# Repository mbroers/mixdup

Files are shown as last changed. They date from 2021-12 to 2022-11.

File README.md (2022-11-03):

# mixdup
teensy based midi controller

Based on the awesome [Control Surface](https://github.com/tttapa/Control-Surface) teensyduino library.

v1 has two rows of switches and uses teensy 3.2

v2 has 3 rows of switches, ICs moved to back of board so they are socketable (this resulted in a change to the teensy code as well), and the pots/sliders are a bit more spaced out along with some other minor cleanups. Still uses teensy 3.2

v3 is for teensy 4.1

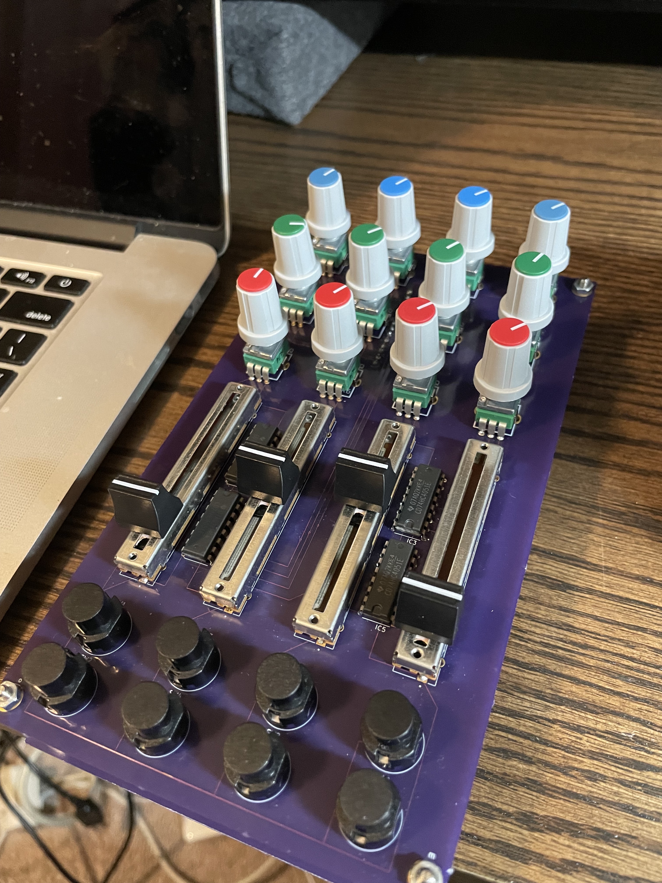
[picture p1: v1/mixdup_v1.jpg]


Forthcoming
- [ ] Panel vector/FPE files
- [ ] Enclosure plans
- [ ] Expander with Effects Racks capabilities and 5 band eq
- [ ] Live macros to create default map

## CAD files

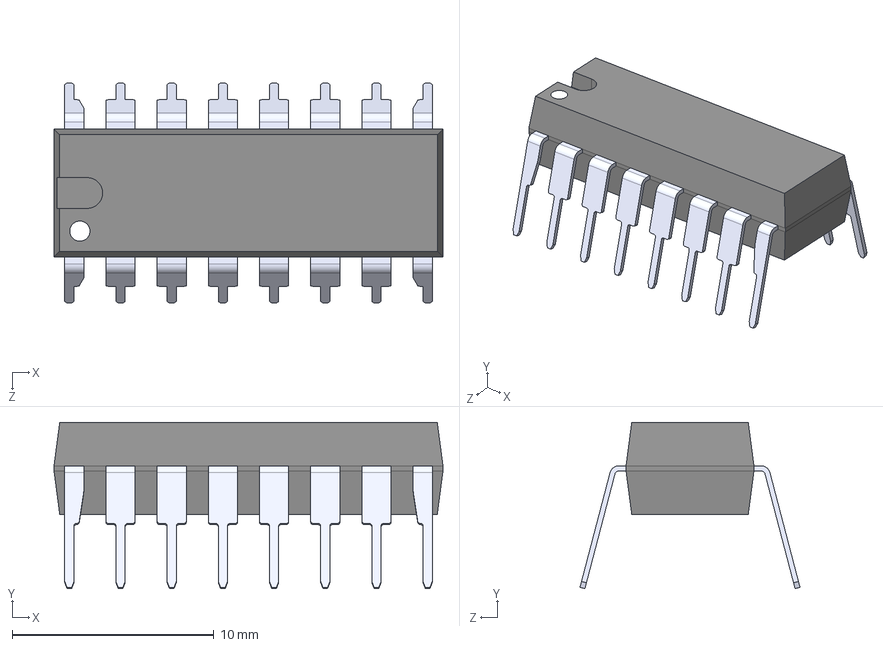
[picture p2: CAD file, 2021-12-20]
kicad_libraries/CD74HC4051E/CD74HC4051E.step
19.3 x 8.25 x 10.9 mm

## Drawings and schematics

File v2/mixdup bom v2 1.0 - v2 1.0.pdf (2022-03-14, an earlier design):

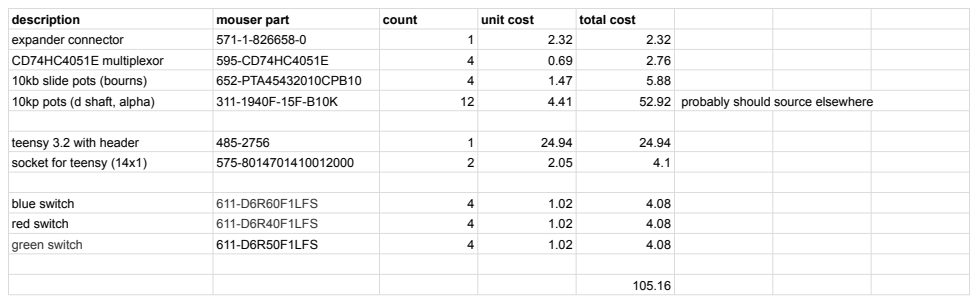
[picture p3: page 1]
description; mouser part; count; unit cost; total cost; expander connector; CD74HC4051E multiplexor; 10kb slide pots (bourns); 652-PTA45432010CPB10; 10kp pots (d shaft, alpha); 52.92 probably should source elsewhere; teensy 3.2 with header; socket for teensy (14x1)

blue switch red switch | 611-D6R60F1LFS 611-D6R40F1LFS | 4 1.02 4.08

green switch | 611-D6R50F1LFS 4 1.02 4.08

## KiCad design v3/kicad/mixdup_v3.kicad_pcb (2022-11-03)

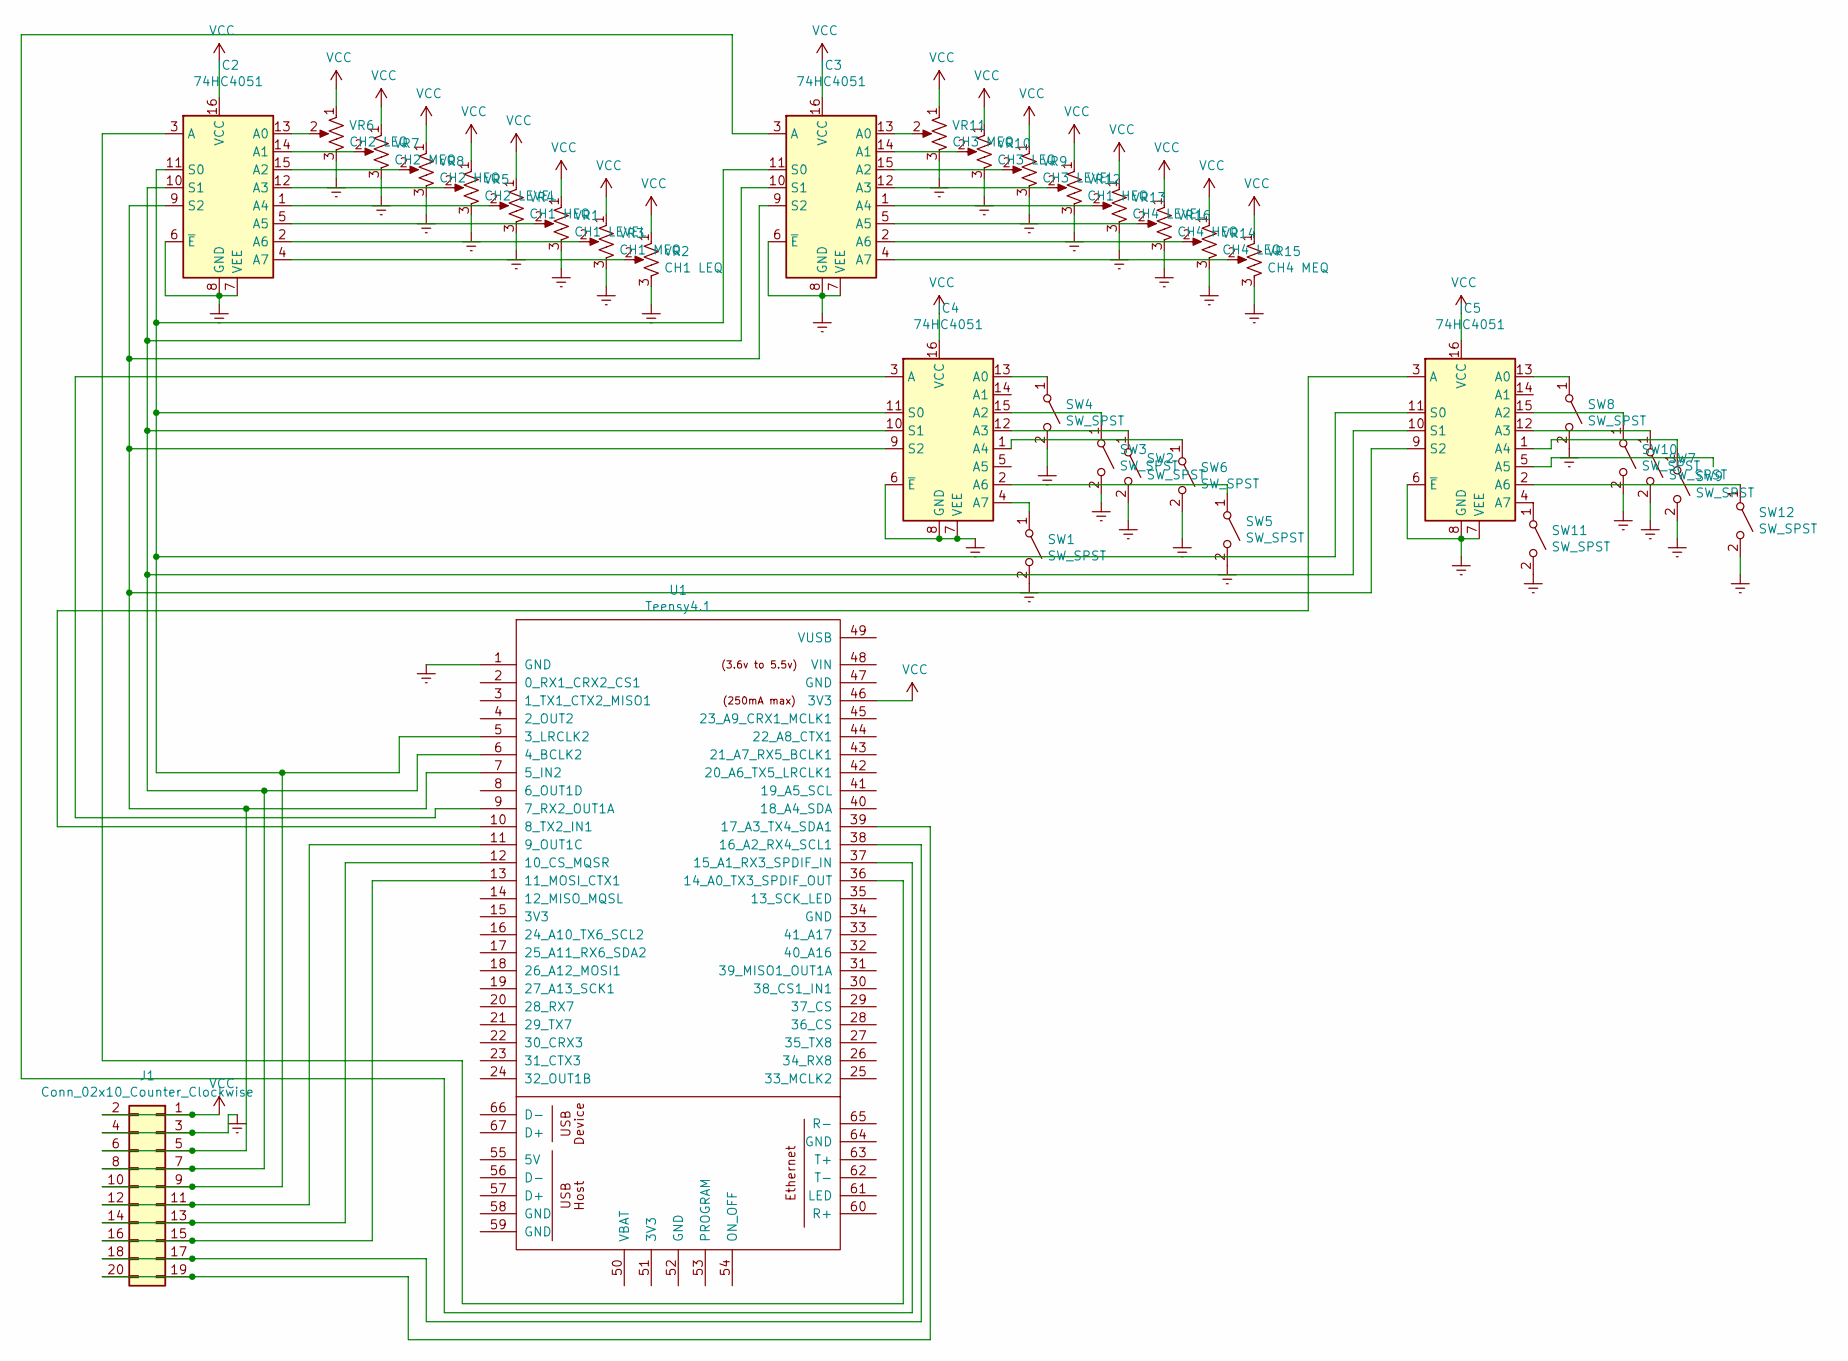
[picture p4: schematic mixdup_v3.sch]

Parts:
IC2, IC3, IC4, IC5: 74HC4051; DIP794W45P254L1969H508Q16
J1: Conn_02x10_Counter_Clockwise; PinHeader_2x10_P2.54mm_Vertical
SW1, SW2, SW3, SW4, SW5, SW6, SW7, SW8, SW9, SW10, SW11, SW12: SW_SPST; SW_D6R90_F1_LFS
U1: Teensy4.1; Teensy41
VR1: CH1 LEVEL; PTA4543-2015DPA103
VR2: CH1 LEQ; RD901F-ALPHA-POT
VR3: CH1 MEQ; RD901F-ALPHA-POT
VR4, VR12: CH1 HEQ; RD901F-ALPHA-POT
VR5: CH2 LEVEL; PTA4543-2015DPA103
VR6: CH2 LEQ; RD901F-ALPHA-POT
VR7: CH2 MEQ; RD901F-ALPHA-POT
VR8: CH2 HEQ; RD901F-ALPHA-POT
VR9: CH3 LEVEL; PTA4543-2015DPA103
VR10: CH3 LEQ; RD901F-ALPHA-POT
VR11: CH3 MEQ; RD901F-ALPHA-POT
VR13: CH4 LEVEL; PTA4543-2015DPA103
VR14: CH4 LEQ; RD901F-ALPHA-POT
VR15: CH4 MEQ; RD901F-ALPHA-POT
VR16: CH4 HEQ; RD901F-ALPHA-POT

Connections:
Earth: IC2.6 (~E), IC2.7 (VEE), IC2.8 (GND), IC3.6 (~E), IC3.7 (VEE), IC3.8 (GND), IC4.6 (~E), IC4.7 (VEE), IC4.8 (GND), IC5.6 (~E), IC5.7 (VEE), IC5.8 (GND), J1.3, J1.4, SW1.2 (B), SW2.2 (B), SW3.2 (B), SW4.2 (B), SW5.2 (B), SW6.2 (B), SW7.2 (B), SW8.2 (B), SW9.2 (B), SW10.2 (B), SW11.2 (B), SW12.2 (B), U1.1 (GND), VR1.3, VR2.3, VR3.3, VR4.3, VR5.3, VR6.3, VR7.3, VR8.3, VR9.3, VR10.3, VR11.3, VR12.3, VR13.3, VR14.3, VR15.3, VR16.3
unnamed: IC2.1 (A4), VR4.2
unnamed: IC2.2 (A6), VR3.2
unnamed: IC2.3 (A), U1.36 (14_A0_TX3_SPDIF_OUT)
unnamed: IC2.4 (A7), VR2.2
unnamed: IC2.5 (A5), VR1.2
unnamed: IC2.9 (S2), IC3.9 (S2), IC4.9 (S2), IC5.9 (S2), J1.5, J1.6, U1.7 (5_IN2)
unnamed: IC2.10 (S1), IC3.10 (S1), IC4.10 (S1), IC5.10 (S1), J1.7, J1.8, U1.6 (4_BCLK2)
unnamed: IC2.11 (S0), IC3.11 (S0), IC4.11 (S0), IC5.11 (S0), J1.9, J1.10, U1.5 (3_LRCLK2)
unnamed: IC2.12 (A3), VR5.2
unnamed: IC2.13 (A0), VR6.2
unnamed: IC2.14 (A1), VR7.2
unnamed: IC2.15 (A2), VR8.2
unnamed: IC3.1 (A4), VR13.2
unnamed: IC3.2 (A6), VR14.2
unnamed: IC3.3 (A), U1.37 (15_A1_RX3_SPDIF_IN)
unnamed: IC3.4 (A7), VR15.2
unnamed: IC3.5 (A5), VR16.2
unnamed: IC3.12 (A3), VR12.2
unnamed: IC3.13 (A0), VR11.2
unnamed: IC3.14 (A1), VR10.2
unnamed: IC3.15 (A2), VR9.2
unnamed: IC4.1 (A4), SW6.1 (A)
unnamed: IC4.2 (A6), SW5.1 (A)
unnamed: IC4.3 (A), U1.9 (7_RX2_OUT1A)
unnamed: IC4.4 (A7), SW1.1 (A)
unnamed: IC4.12 (A3), SW2.1 (A)
unnamed: IC4.13 (A0), SW4.1 (A)
unnamed: IC4.15 (A2), SW3.1 (A)
unnamed: IC5.1 (A4), SW9.1 (A)
unnamed: IC5.2 (A6), SW12.1 (A)
unnamed: IC5.3 (A), U1.10 (8_TX2_IN1)
unnamed: IC5.4 (A7), SW11.1 (A)
unnamed: IC5.12 (A3), SW7.1 (A)
unnamed: IC5.13 (A0), SW8.1 (A)
unnamed: IC5.15 (A2), SW10.1 (A)
unnamed: J1.11, J1.12, U1.11 (9_OUT1C)
unnamed: J1.13, J1.14, U1.12 (10_CS_MQSR)
unnamed: J1.15, J1.16, U1.13 (11_MOSI_CTX1)
unnamed: J1.17, J1.18, U1.38 (16_A2_RX4_SCL1)
unnamed: J1.19, J1.20, U1.39 (17_A3_TX4_SDA1)
VCC: IC2.16 (VCC), IC3.16 (VCC), IC4.16 (VCC), IC5.16 (VCC), J1.1, J1.2, U1.46 (3V3), VR1.1, VR2.1, VR3.1, VR4.1, VR5.1, VR6.1, VR7.1, VR8.1, VR9.1, VR10.1, VR11.1, VR12.1, VR13.1, VR14.1, VR15.1, VR16.1

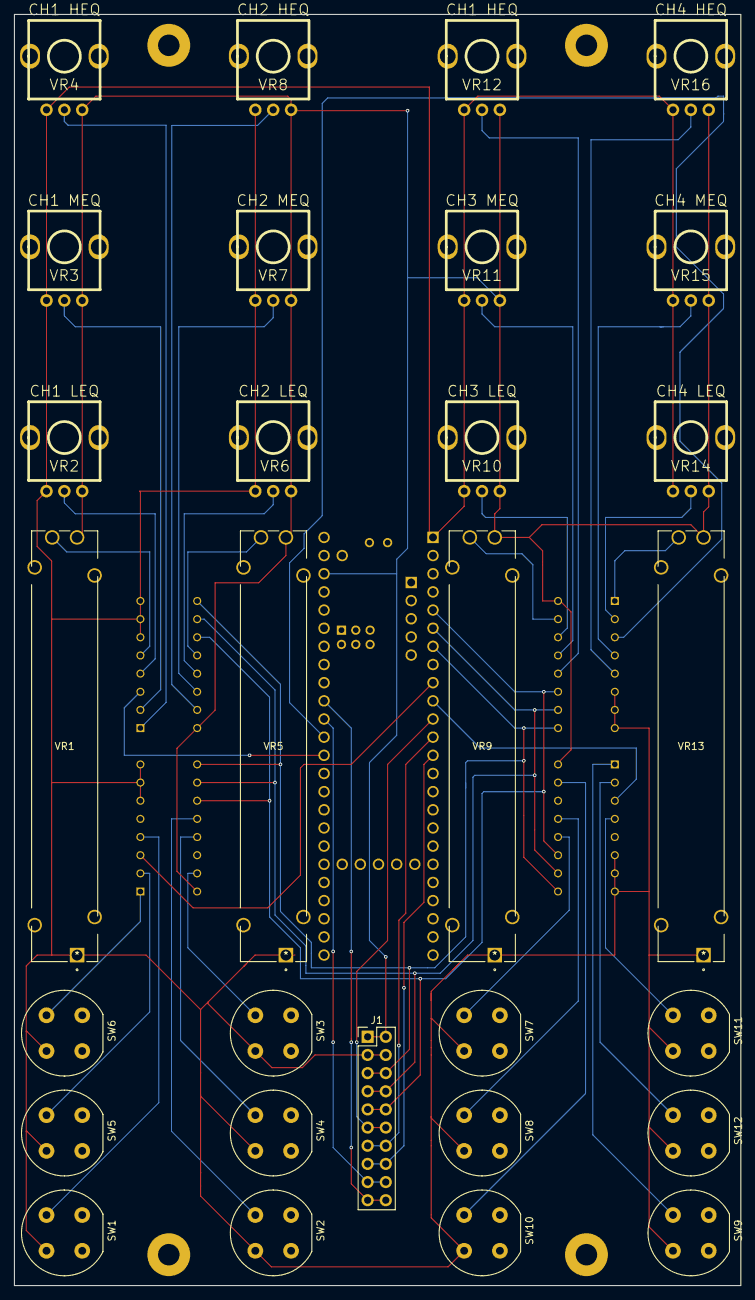
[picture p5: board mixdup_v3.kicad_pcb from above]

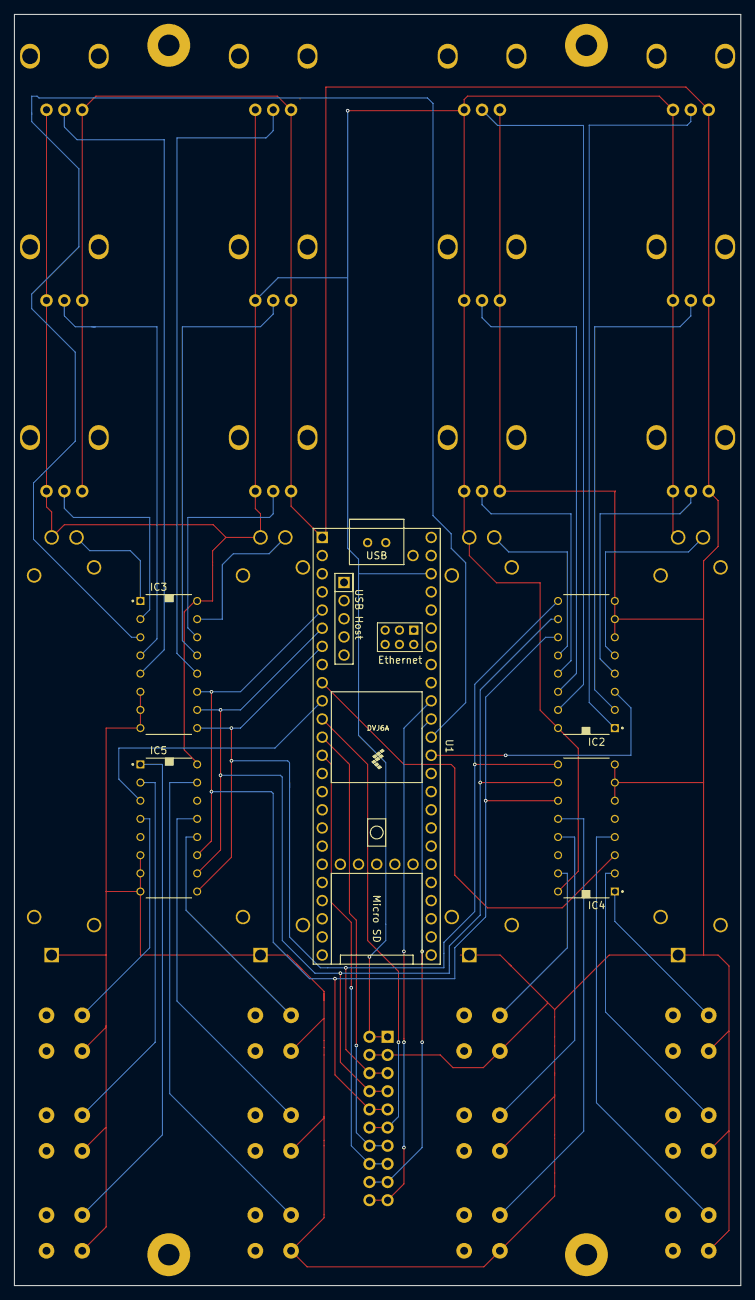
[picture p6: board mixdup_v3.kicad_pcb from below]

Board: 2 copper layers, 101.6 x 177.8 mm, 34 parts (5 on the bottom side), 42 nets.

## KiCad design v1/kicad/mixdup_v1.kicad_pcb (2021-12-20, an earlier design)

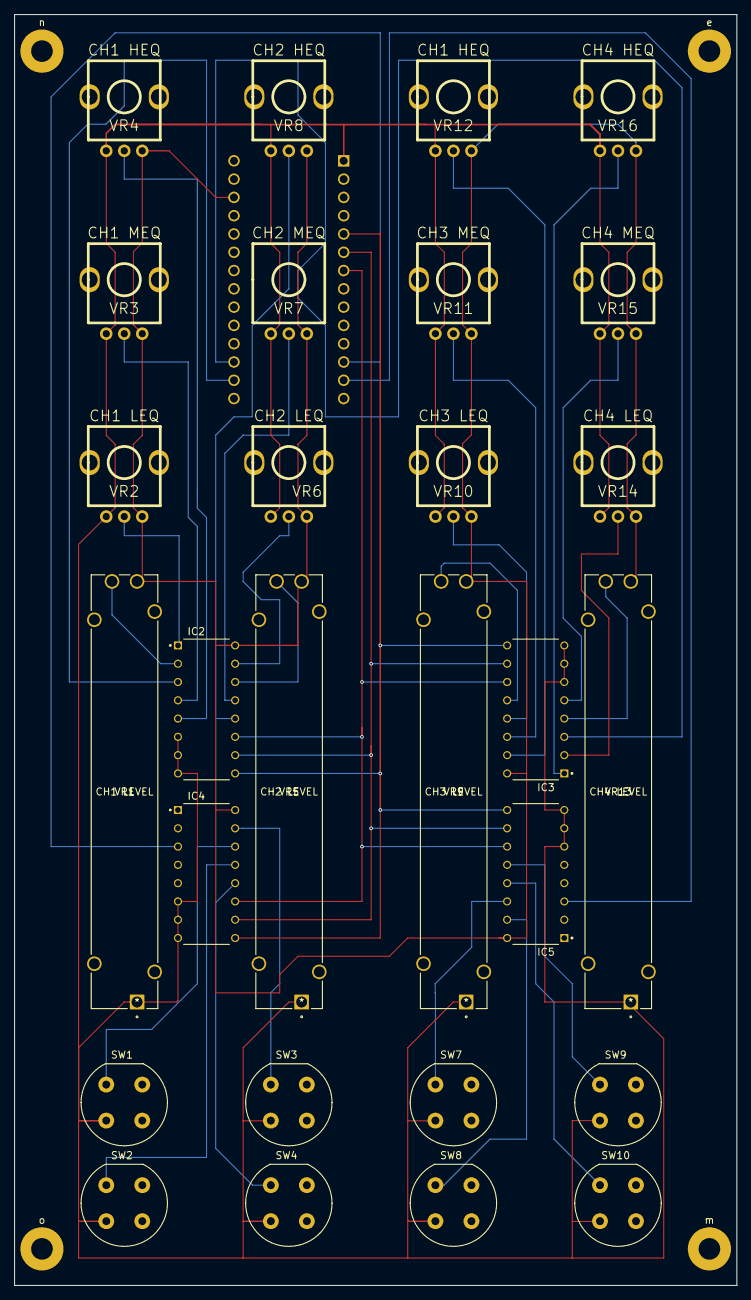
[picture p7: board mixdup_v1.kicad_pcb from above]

Board: 2 copper layers, 100.3 x 176.5 mm, 33 parts (1 on the bottom side), 33 nets.

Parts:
IC1: Teensy3.2; Teensy30_31_32_Some_Pins_MB
IC2, IC3, IC4, IC5: 74HC4051; DIP794W45P254L1969H508Q16
SW1, SW2, SW3, SW4, SW7, SW8, SW9, SW10: SW_SPST; SW_D6R90_F1_LFS
VR1: CH1 LEVEL; PTA4543-2015DPA103
VR2: CH1 LEQ; RD901F-ALPHA-POT
VR3: CH1 MEQ; RD901F-ALPHA-POT
VR4, VR12: CH1 HEQ; RD901F-ALPHA-POT
VR5: CH2 LEVEL; PTA4543-2015DPA103
VR6: CH2 LEQ; RD901F-ALPHA-POT
VR7: CH2 MEQ; RD901F-ALPHA-POT_MB_overteensy
VR8: CH2 HEQ; RD901F-ALPHA-POT
VR9: CH3 LEVEL; PTA4543-2015DPA103
VR10: CH3 LEQ; RD901F-ALPHA-POT
VR11: CH3 MEQ; RD901F-ALPHA-POT
VR13: CH4 LEVEL; PTA4543-2015DPA103
VR14: CH4 LEQ; RD901F-ALPHA-POT
VR15: CH4 MEQ; RD901F-ALPHA-POT
VR16: CH4 HEQ; RD901F-ALPHA-POT
e: e; MountingHole_3mm_Pad
m: m; MountingHole_3mm_Pad
n: n; MountingHole_3mm_Pad
o: o; MountingHole_3mm_Pad

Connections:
Earth: IC1.1, IC2.6, IC2.7, IC2.8, IC3.6, IC3.7, IC3.8, IC4.6, IC4.7, IC4.8, IC5.6, IC5.7, IC5.8, SW1.2, SW2.2, SW3.2, SW4.2, SW7.2, SW8.2, SW9.2, SW10.2, VR1.3, VR2.3, VR3.3, VR4.3, VR5.3, VR6.3, VR7.3, VR8.3, VR9.3, VR10.3, VR11.3, VR12.3, VR13.3, VR14.3, VR15.3, VR16.3
unnamed: IC1.5, IC2.9, IC3.9, IC4.9, IC5.9
unnamed: IC1.6, IC2.10, IC3.10, IC4.10, IC5.10
unnamed: IC1.7, IC2.11, IC3.11, IC4.11, IC5.11
unnamed: IC1.12, IC4.3
unnamed: IC1.13, IC5.3
unnamed: IC1.21, IC2.3
unnamed: IC1.22, IC3.3
unnamed: IC2.1, VR2.2
unnamed: IC2.2, VR1.2
unnamed: IC2.4, VR3.2
unnamed: IC2.5, VR4.2
unnamed: IC2.12, VR8.2
unnamed: IC2.13, VR7.2
unnamed: IC2.14, VR5.2
unnamed: IC2.15, VR6.2
unnamed: IC3.1, VR16.2
unnamed: IC3.2, VR14.2
unnamed: IC3.4, VR13.2
unnamed: IC3.5, VR15.2
unnamed: IC3.12, VR9.2
unnamed: IC3.13, VR10.2
unnamed: IC3.14, VR11.2
unnamed: IC3.15, VR12.2
unnamed: IC4.12, SW4.1
unnamed: IC4.13, SW2.1
unnamed: IC4.14, SW1.1
unnamed: IC4.15, SW3.1
unnamed: IC5.12, SW9.1
unnamed: IC5.13, SW10.1
unnamed: IC5.14, SW7.1
unnamed: IC5.15, SW8.1
VCC: IC1.31, IC2.16, IC3.16, IC4.16, IC5.16, VR1.1, VR2.1, VR3.1, VR4.1, VR5.1, VR6.1, VR7.1, VR8.1, VR9.1, VR10.1, VR11.1, VR12.1, VR13.1, VR14.1, VR15.1, VR16.1

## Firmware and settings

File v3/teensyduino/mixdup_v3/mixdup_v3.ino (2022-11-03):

#include <Control_Surface.h>

USBMIDI_Interface mixdup;

CD74HC4051 mux1 {
  A0,       // Analog input pin
  {3, 4, 5} // Address pins S0, S1, S2
};

CD74HC4051 mux2 {
  7,       // digital input pin
  {3, 4, 5} // Address pins S0, S1, S2
};

CD74HC4051 mux3 {
  A1,       // Analog input pin
  {3, 4, 5} // Address pins S0, S1, S2
};

CD74HC4051 mux4 {
  8,       // digital input pin
  {3, 4, 5} // Address pins S0, S1, S2
};


CCPotentiometer volumePotentiometers [] {
  { mux1.pin(0), { MIDI_CC::Channel_Volume, CHANNEL_1 } },
  { mux1.pin(1), { MIDI_CC::Channel_Volume, CHANNEL_2 } },
  { mux1.pin(2), { MIDI_CC::Channel_Volume, CHANNEL_3 } },
  { mux1.pin(3), { MIDI_CC::Channel_Volume, CHANNEL_4 } },
  { mux1.pin(4), { MIDI_CC::Channel_Volume, CHANNEL_5 } },
  { mux1.pin(5), { MIDI_CC::Channel_Volume, CHANNEL_6 } },
  { mux1.pin(6), { MIDI_CC::Channel_Volume, CHANNEL_7 } },
  { mux1.pin(7), { MIDI_CC::Channel_Volume, CHANNEL_8 } },
  { mux3.pin(0), { MIDI_CC::Channel_Volume, CHANNEL_9 } },
  { mux3.pin(1), { MIDI_CC::Channel_Volume, CHANNEL_10 } },
  { mux3.pin(2), { MIDI_CC::Channel_Volume, CHANNEL_11 } },
  { mux3.pin(3), { MIDI_CC::Channel_Volume, CHANNEL_12 } },
  { mux3.pin(4), { MIDI_CC::Channel_Volume, CHANNEL_13 } },
  { mux3.pin(5), { MIDI_CC::Channel_Volume, CHANNEL_14 } },
  { mux3.pin(6), { MIDI_CC::Channel_Volume, CHANNEL_15 } },
  { mux3.pin(7), { MIDI_CC::Channel_Volume, CHANNEL_16 } }
};


CCButtonLatched pushme[] {
  { mux2.pin(4), { MIDI_CC::General_Purpose_Controller_1, CHANNEL_5} },
  { mux2.pin(7), { MIDI_CC::General_Purpose_Controller_1, CHANNEL_6} },
  { mux2.pin(2), { MIDI_CC::General_Purpose_Controller_1, CHANNEL_7} },
  { mux2.pin(3), { MIDI_CC::General_Purpose_Controller_1, CHANNEL_8} },
  { mux4.pin(3), { MIDI_CC::General_Purpose_Controller_1, CHANNEL_9} },
  { mux4.pin(2), { MIDI_CC::General_Purpose_Controller_1, CHANNEL_10} },
  { mux4.pin(7), { MIDI_CC::General_Purpose_Controller_1, CHANNEL_11} },
  { mux4.pin(4), { MIDI_CC::General_Purpose_Controller_1, CHANNEL_12} },
};

CCButton launchpad[] {
  { mux2.pin(6), { MIDI_CC::General_Purpose_Controller_1, CHANNEL_1} },
  { mux2.pin(0), { MIDI_CC::General_Purpose_Controller_1, CHANNEL_2} },
  { mux4.pin(0), { MIDI_CC::General_Purpose_Controller_1, CHANNEL_3} },
  { mux4.pin(6), { MIDI_CC::General_Purpose_Controller_1, CHANNEL_4} },
};

void setup() {
  Control_Surface.begin();
}

void loop() {
  Control_Surface.loop();
}

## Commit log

2022-01-30 components spaced out
    [mixdup_v2.kicad_pcb]
2022-02-08 better spacing, ICs on back
    [mixdup_v2.kicad_pcb, mixdup_v2.sch]
2022-02-15 prototype ics on back better distro
    [mixdup_v2.kicad_pcb]
2022-03-03 adding teensyduino file for v2
2022-03-06 fixed incorrect switch assignments
    [mixdup_v2.ino]
2022-03-14 adding bom for v2
2022-11-03 checkpoint - kicad great, panel needs tweaking
    [mixdup_v3.kicad_pcb, mixdup_v3.sch]
2022-11-03 updating for reference to teensy 4.1

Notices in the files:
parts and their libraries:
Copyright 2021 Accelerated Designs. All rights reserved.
